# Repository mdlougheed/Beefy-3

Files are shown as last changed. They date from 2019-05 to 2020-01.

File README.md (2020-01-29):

# Meaty-3+
Meaty-3+ is a micro USB connected Basic Breakout for the FTDI FT231XS USB to serial IC. It's a "springboard" from the Sparkfun "Beefy-3" USB-Serial board with some additional capabilities.

Version 3 includes an improved micro-USB plug and updated documents.

Boards are available from OSH Park:
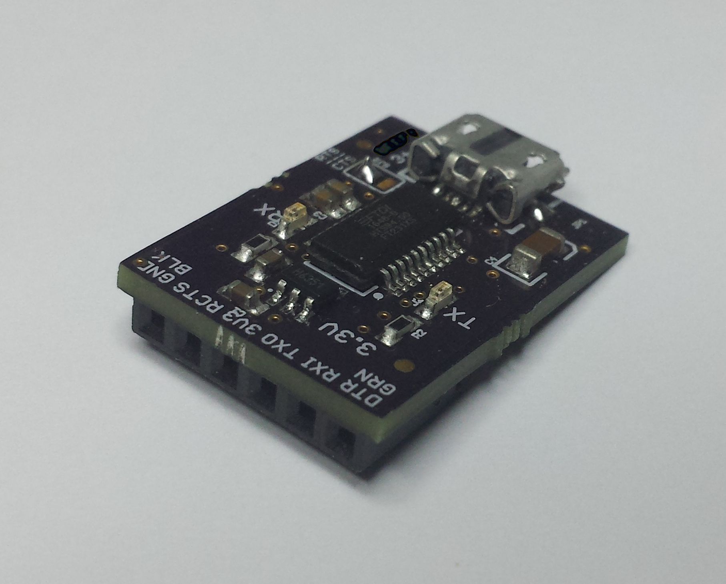
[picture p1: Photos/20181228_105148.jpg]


The Meaty-3+ brings more power output, using a Torex Semiconductor 1 Amp XC6220B331MR-G linear 3.3V regulator. That's a whopping 66% power output increase (up to your USB power supply current limit - of course)! It also features on-board selectable CTS input or RTS output using a solder jumper.

This board will auto-reset any Arduino board that has the (DTR) reset pin brought out to a 6-pin connector (Arduino, Lilypad, etc) - AND can be configured for auto-resetting boards that use the RTS signal, as well as auto-reset/auto-program ESP-8266 & EPS-32 based boards that use the NodeMCU style DTR/RTS transistor crossover reset circuit (NodeMCU, ESP8266, ESP-01, Huzzah). In other words, you have flexibility!

This pluggable serial adapter, simplifies your application board when the power and cost expense of USB serial connectivity isn't always needed.

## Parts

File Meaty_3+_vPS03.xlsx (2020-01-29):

Qty | Value | Device | Package | Parts | Description | PROD_ID | VALUE
1 |  | M06SMD-FEMALE-V2 | 1X06-SMD-FEMALE-V2 | JP2 | Header 6 | CONN-09668
1 |  | USB_MICROB_PLUG | USB-B-MICRO-SMD | JP1 | Wurth 629105136821 (Digikey 732-3155-1-ND) | WE629105136821
2 | 0.1uF | 0.1UF-25V(+80/-20%)(0603) | 0603-CAP | C3
2 | 1.0uF | 1.0UF-16V-10%(0603) | 0603-CAP | C1
1 | 10uF | 10UF-16V-10%(TANT) | EIA3216 | C4 | CAP-00811 | CAP-00811 | 10uF
2 | 1K | 1KOHM-1/10W-1%(0603) | 0603-RES | R1
1 | 3.3V | V_REG_AP2112K-3.3V | SOT23-5 | U1 | AP2112 - 600mA CMOS LDO Regulator w/ Enable | VREG-12457 | 3.3V
1 | FTS31XS-U | FT231XS | SSOP20_L | U2 | FTDI FT231X Full Speed USB to Full-handshake UART | IC-11524 | FTS31XS-U
1 | GREEN | LED-GREEN0603 | LED-0603 | D1 | Various green LEDs | DIO-00821 | GREEN
1 | RED | LED-RED0603 | LED-0603 | D2 | Assorted Red LEDs | DIO-00819 | RED

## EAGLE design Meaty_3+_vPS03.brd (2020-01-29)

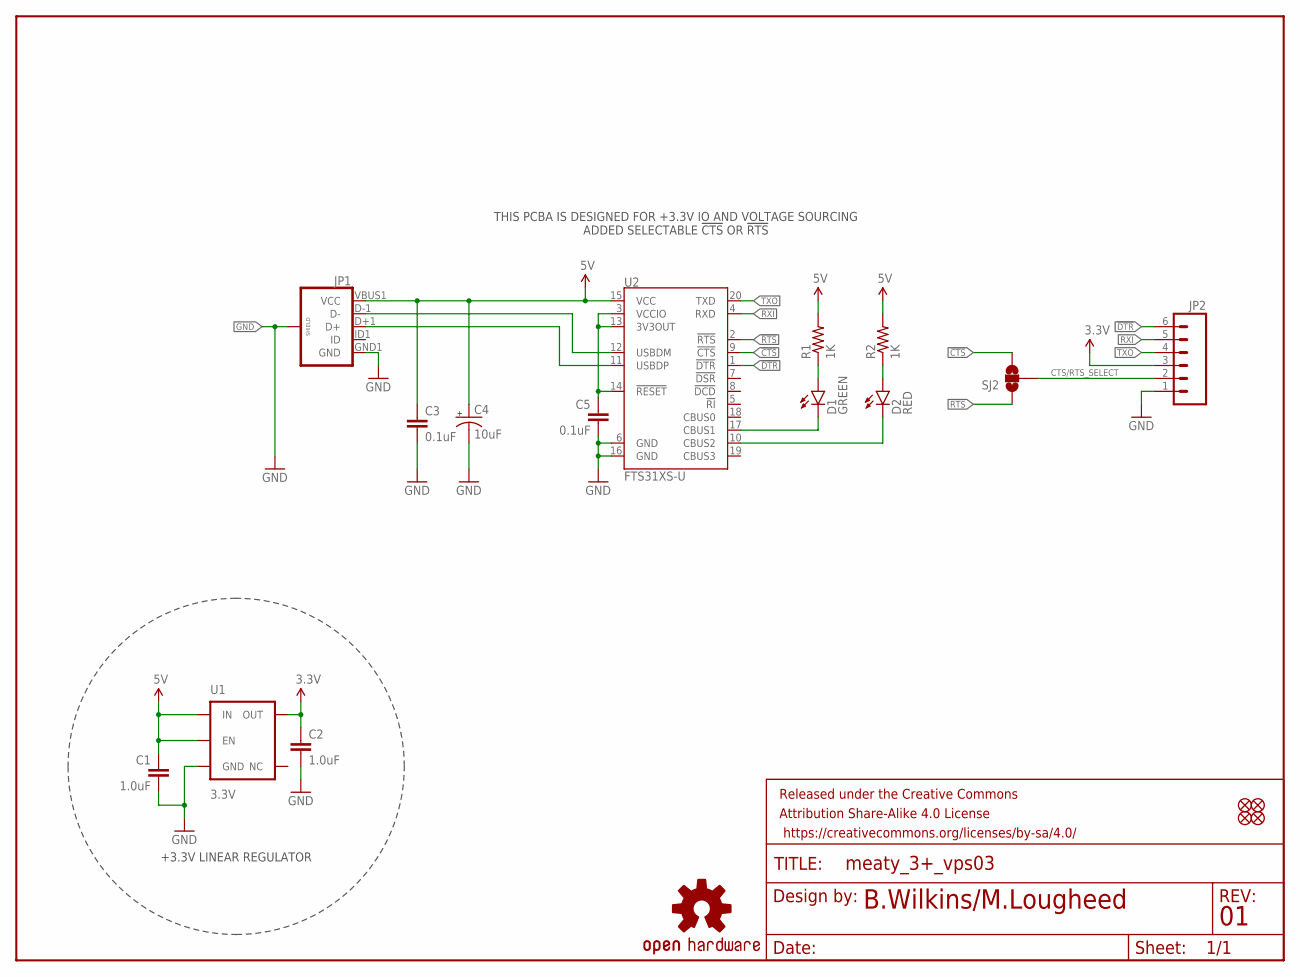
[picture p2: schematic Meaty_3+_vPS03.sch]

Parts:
C1, C2: 1.0uF; 0603-CAP
C3, C5: 0.1uF; 0603-CAP
C4: 10uF; EIA3216
D1: GREEN; LED-0603
D2: RED; LED-0603
FRAME1: FRAME-LETTER; CREATIVE_COMMONS
JP1: USB_MICROB_PLUGWE629105136821; MICRO-USB-2.0-B-SMT
JP2: M06SMD-FEMALE-V2; 1X06-SMD-FEMALE-V2
JP3, JP4, JP5, JP6: FIDUCIAL1X2; FIDUCIAL-1X2
LOGO1: OSHW-LOGOS; OSHW-LOGO-S
R1, R2: 1K; 0603-RES
SJ2: SOLDERJUMPER_2WAYS; SJ_3
U1: 3.3V; SOT23-5
U2: FTS31XS-U; SSOP20_L

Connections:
3V3: C2.1, JP2.3, U1.5 (OUT)
3V3LC: C5.1, U2.3 (VCCIO), U2.13 (3V3OUT), U2.14 (!RESET)
5V: C1.1, C3.1, C4.A (+), JP1.VBUS1 (VCC), R1.2, R2.2, U1.1 (IN), U1.3 (EN), U2.15 (VCC)
!CTS: SJ2.3, U2.9 (!CTS)
!DTR: JP2.6, U2.1 (!DTR)
!RTS: SJ2.1, U2.2 (!RTS)
CTS/RTS_SELECT: JP2.2, SJ2.2
GND: C1.2, C2.2, C3.2, C4.C (-), C5.2, JP1.GND1 (GND), JP1.SHIELD0 (SHIELD), JP1.SHIELD1 (SHIELD), JP1.SHIELD3 (SHIELD), JP2.1, U1.2 (GND), U2.6 (GND), U2.16 (GND)
unnamed: D2.A, R2.1
unnamed: D1.A, R1.1
RXI: JP2.5, U2.4 (RXD)
RXLED: D1.C, U2.17 (CBUS1)
TXLED: D2.C, U2.10 (CBUS2)
TXO: JP2.4, U2.20 (TXD)
USB_D+: JP1.D+1 (D+), U2.11 (USBDP)
USB_D-: JP1.D-1 (D-), U2.12 (USBDM)

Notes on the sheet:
+3.3V LINEAR REGULATOR
THIS PCBA IS DESIGNED FOR +3.3V IO AND VOLTAGE SOURCING ADDED SELECTABLE !CTS! OR !RTS!

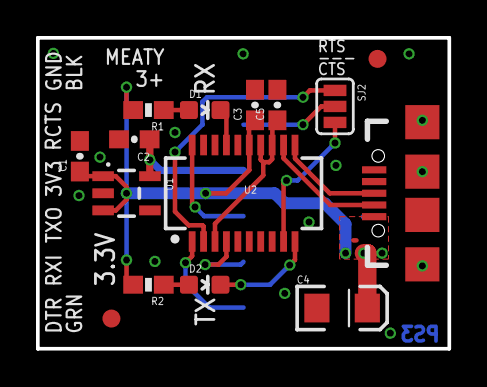
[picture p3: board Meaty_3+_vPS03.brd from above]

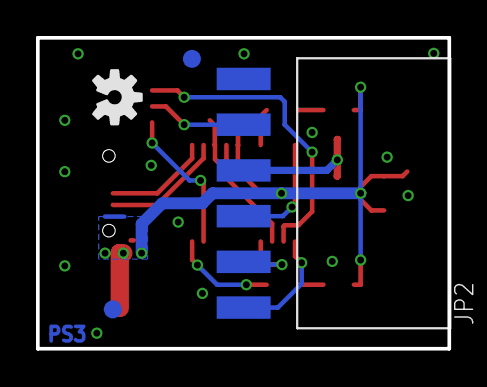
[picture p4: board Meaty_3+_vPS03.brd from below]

Board: 2 copper layers, 22.9 x 17.3 mm, 20 parts (4 on the bottom side), 16 nets.

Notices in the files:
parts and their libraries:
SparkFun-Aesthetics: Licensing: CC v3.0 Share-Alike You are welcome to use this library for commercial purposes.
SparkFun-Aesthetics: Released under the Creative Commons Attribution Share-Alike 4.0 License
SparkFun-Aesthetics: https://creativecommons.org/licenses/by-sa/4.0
